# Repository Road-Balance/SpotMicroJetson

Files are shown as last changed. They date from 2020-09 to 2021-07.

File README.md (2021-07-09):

# SpotMicroAI - Road Balance version

### news
- There's Full video instruction about this project [youtube link](https://www.youtube.com/watch?v=RocfxXIWZd4&list=PLK2UKp8KOXe1ZRbSmcO3VvE_TNs66K6lA)
- And also there's Notion Note for whole project process [Notion Link](https://www.notion.so/SpotMicro-for-G-Camp-c541934a4bad4ad48d1e37ab94c10de8) 
- Those Contents above are written in Korean

SpotForward

## Abstract:

Let's build quadruped robot. Only requires few low-cost parts and this repository :)

## Hardware:

<center>
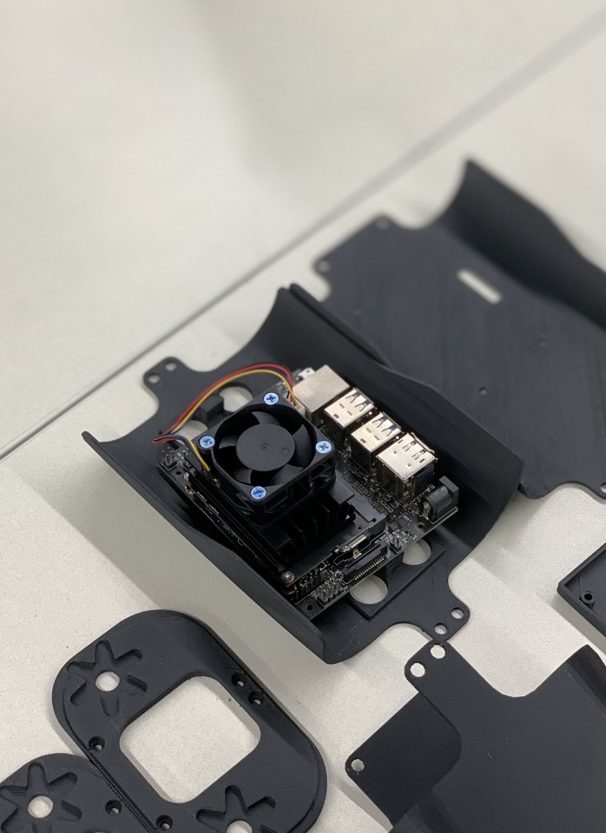
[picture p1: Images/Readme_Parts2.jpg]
    
</center>

The hardware for SpotMicroAI is designed to be both aesthetically pleasing as well as easily obtainable and readily available. Wherever possible standard screws, bolts, and bearings are used. Standard hobby grade servos are currently used for locomotion in development however, they don't appear to have sufficient power to drive the robot at more than the slowest speeds. Other options are currently being investigated (including high-voltage and brushless hobby servos typically used with RC cars) which we hope will lead to a balance between an economical as well as robust robot.

The vast majority of the hardware by volume is designed to be 3D printed. So far complete prints have been successful in PLA, though no technical barriers should exist to printing the robot in other material such as PETG, nylon, ABS, etc. The majority of parts require significant supports to print.

The files available both as STL and STP. As a community we have not yet settled on a servo for this project and therefore multiple versions of the hardware exist to support the physical dimensions of the servos and their respective servo horns. For the most up-to-date version of the hardware please visit: [https://www.thingiverse.com/thing:3761340](https://www.thingiverse.com/thing:3761340). Please see documentation for details as to which files correspond to which servo.

> BOM for Korean Commerce is added and here's the [google spreadsheet link](https://docs.google.com/spreadsheets/d/1UIJ1a0tUQx4ky75Ovr97hnKy3tkcdXQCYJl6zFl0juA/edit?usp=sharing)

## Electronics:

<center>
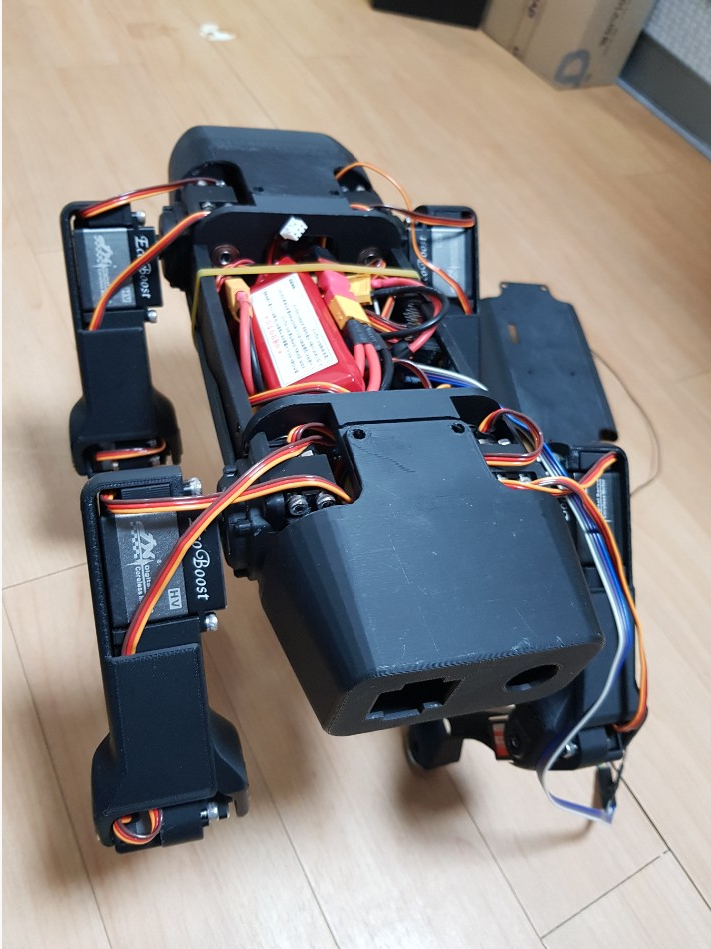
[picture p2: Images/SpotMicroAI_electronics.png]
    
</center>

The `Jetson Nano` operates at 5v, and the `PCA9658` for driving the servomotor operates at 6v. In this project, the electronic department was constructed using 7.9v LiPo batteries and `LM2596` DC Converter.

## PyBullet Simulation:
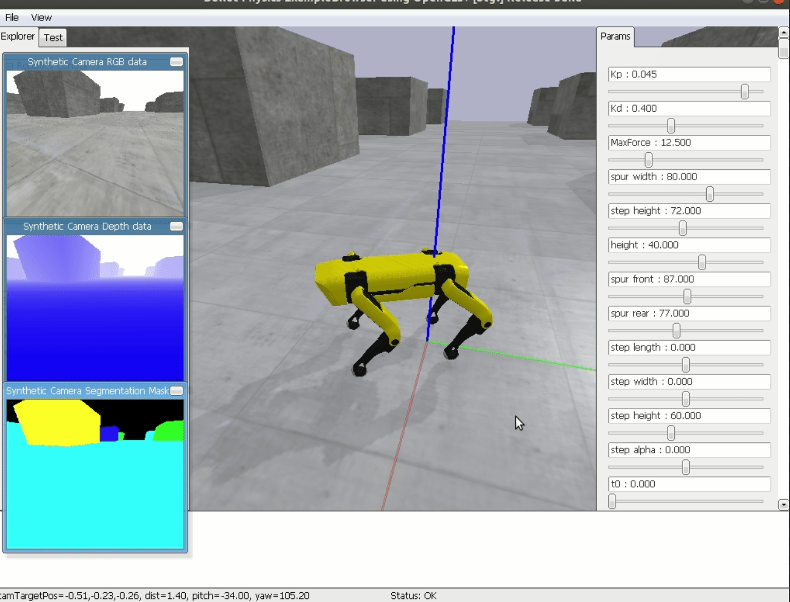
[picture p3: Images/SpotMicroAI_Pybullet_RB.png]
PyBullet Simulation


Before making the actual robot, we recommend experimenting with the kinematics and walking mechanism of the robot through simulation, and added a simulated environment built with pybullets to this end.

The walking mechanism can be understood through the adjustment of several parameters in simulation, and SpotMicro can also be controlled by the keyboard.

## Real Robots

SkyWalk

Finally, it's time to have a real robot and run it. Before uploading and operating the software after assembly, the debugging points such as calibration, center of gravity, and component placement of servo motor are organized and written in Readme file.

---

## Reference && Community

This repository originally forked from [FlorianWilk's Jetson Nano SpotMicro Project](https://github.com/FlorianWilk/SpotMicroAI)

COMPLETE DOCUMENTATION AND GETTING STARTED GUIDES CAN BE FOUND AT:
[https://spotmicroai.readthedocs.io/en/latest/](https://spotmicroai.readthedocs.io/en/latest/)

[spotmicroai.readthedocs.io](http://spotmicroai.readthedocs.io)

The best place to get started is to read the getting started documentation at [spotmicroai.readthedocs.io](spotmicroai.readthedocs.io). The documentation will eventually contain a complete tutorial for building a SpotMicroAI including where to source components, links to most recent 3D files for printing, assembly, and installing the software. It's being updated as we go.

For questions or more information please see the [Forums at SpotMicroAI.org](http://SpotMicroAI.org), or asked on slack. Join our slack at: [https://spotmicroai-inviter.herokuapp.com/](https://spotmicroai-inviter.herokuapp.com/)



BostonDynamics Spot robot: https://www.youtube.com/watch?v=wlkCQXHEgjA

Can you make it dance? join the challenge: https://www.youtube.com/watch?v=kHBcVlqpvZ8&list=PLp5v7U2tXHs3BYfe93GZwuUZLGsisapic&index=2

Original idea by KDY0523 https://www.thingiverse.com/thing:3445283

Some of the community videos: https://www.youtube.com/playlist?list=PLp5v7U2tXHs3BYfe93GZwuUZLGsisapic

* Join us in Slack: https://spotmicroai-inviter.herokuapp.com/
* Documentation: https://spotmicroai.readthedocs.io
* Forum http://spotmicroai.org/

This is the repository for simulation code, usually in combination with nVIDIA Jetson Nano board, of SpotMicro project.

In here you can find all the project repositories: **https://gitlab.com/custom_robots/spotmicro**

### Community:
The primary community discussions take place on SpotMicro.org. The message boards there contain a repository of topics which span hardware and software.

Real-time question-and-answer (or as close to real time as is possible when run by volunteers with full-time jobs and families) can happen on slack (LINK coming soon).

Other questions occasionally surface on other location such as on Thingiverse or on robotshop.com. We do our best answers these as we see them, but if you want to be heard the best way is either on SpotMicro.org or on slack.

As a community we do have some small expenses such as web hosting fees and occasional developing fees. In the future, we would also like to hold events and competitions. To anyone who finds enjoyment or education in this project we appreciate the financial support you're able to give. Donations coming soon.

All donations stay in the community and go towards future development.

If you use this worker will any work derived from it in academic publication please cite it as: *insert citation here*.

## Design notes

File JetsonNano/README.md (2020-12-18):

## SpotMicroAI for JetsonNano

TODO: Update this documentation

The Nano will use a 16 Channel PCA9685 I2C-Servo Driver to drive the 12 Servos for the Legs.
First of all all prepare your Jetson Nano as you see in the NVIDIA Documentation.

Then connect to it via SSH and:

```
$ sudo apt install python-dev python-pip python3-pip libfreetype6-dev libavdevice-dev libavfilter-dev libswscale-dev libavformat-dev libjpeg-dev build-essential -y
$ sudo apt install libsdl-dev libportmidi-dev libsdl-ttf2.0-dev libsdl-mixer1.2-dev libsdl-image1.2-dev -y 

$ pip install --upgrade pip
$ pip install --upgrade setuptools

$ cd SpotMiroAI/JetsonNano
$ pip3 install -U -r requirements.txt 
```

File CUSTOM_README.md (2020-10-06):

# SpotMicroJetson

Let's make SpotMicro with Nvidia Jetson Nano

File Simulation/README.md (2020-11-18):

## SpotMicroAI Pybullet Simulation

auto_gait

## Install Dependencies

```
sudo apt-get install python3 python3-pip
git clone https://github.com/Road-Balance/SpotMicroJetson.git

source <your-env>/bin/activate

cd SpotMicroJetson/Core
pip3 install -U -r requirements.txt 
```

## Automatic Gait with Keyboard Control

keyboard_control

Control SpotMicro in Pybullet Simulation with keyboard buttons 

```
# activate python venv
source <your-env>/bin/activate

# run automatic gait
# this needs administer privileges for keyboard multiprocessing
sudo python3 pybullet_automatic_gait.py

# if you're using venv
sudo <your-env-python-location> pybullet_automatic_gait.py
```

* `w` : go ahead
* `a` : go leftward
* `s` : go backward
* `d` : go rightward
* `q` : turn counter-clockwise
* `e` : turn clockwise
* `space` : Stop

Each time you press a button, it will move harder in that direction.

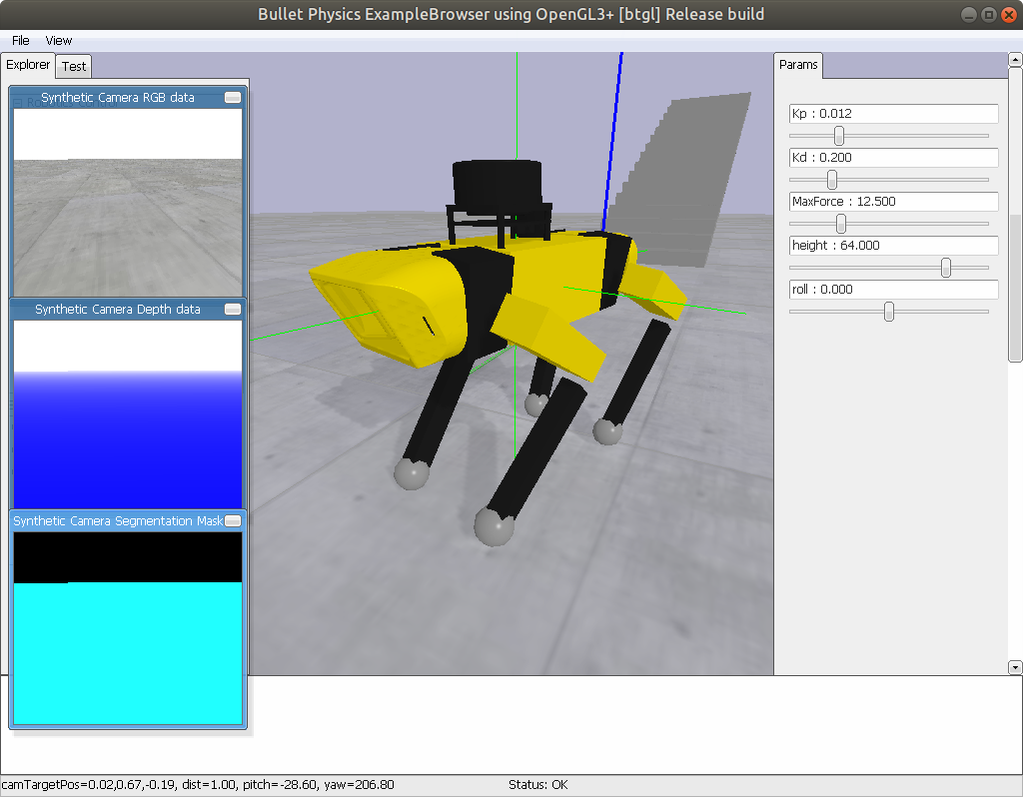
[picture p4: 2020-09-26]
Images/SpotMicroAI_pybullet_lidar.png

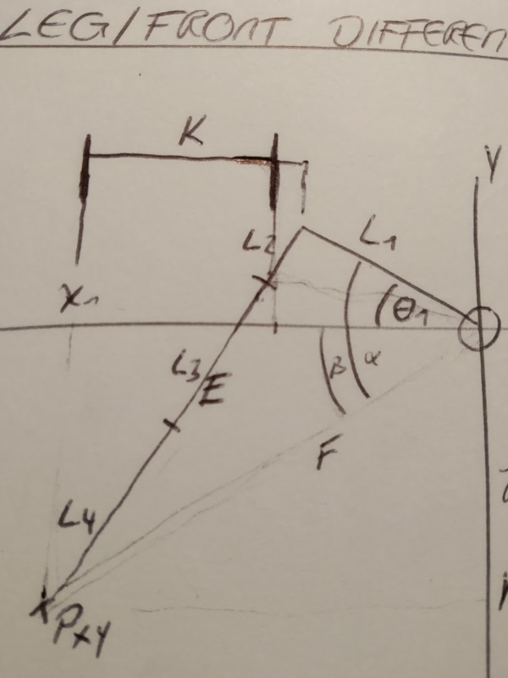
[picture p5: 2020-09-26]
Images/leg_front_k.jpg

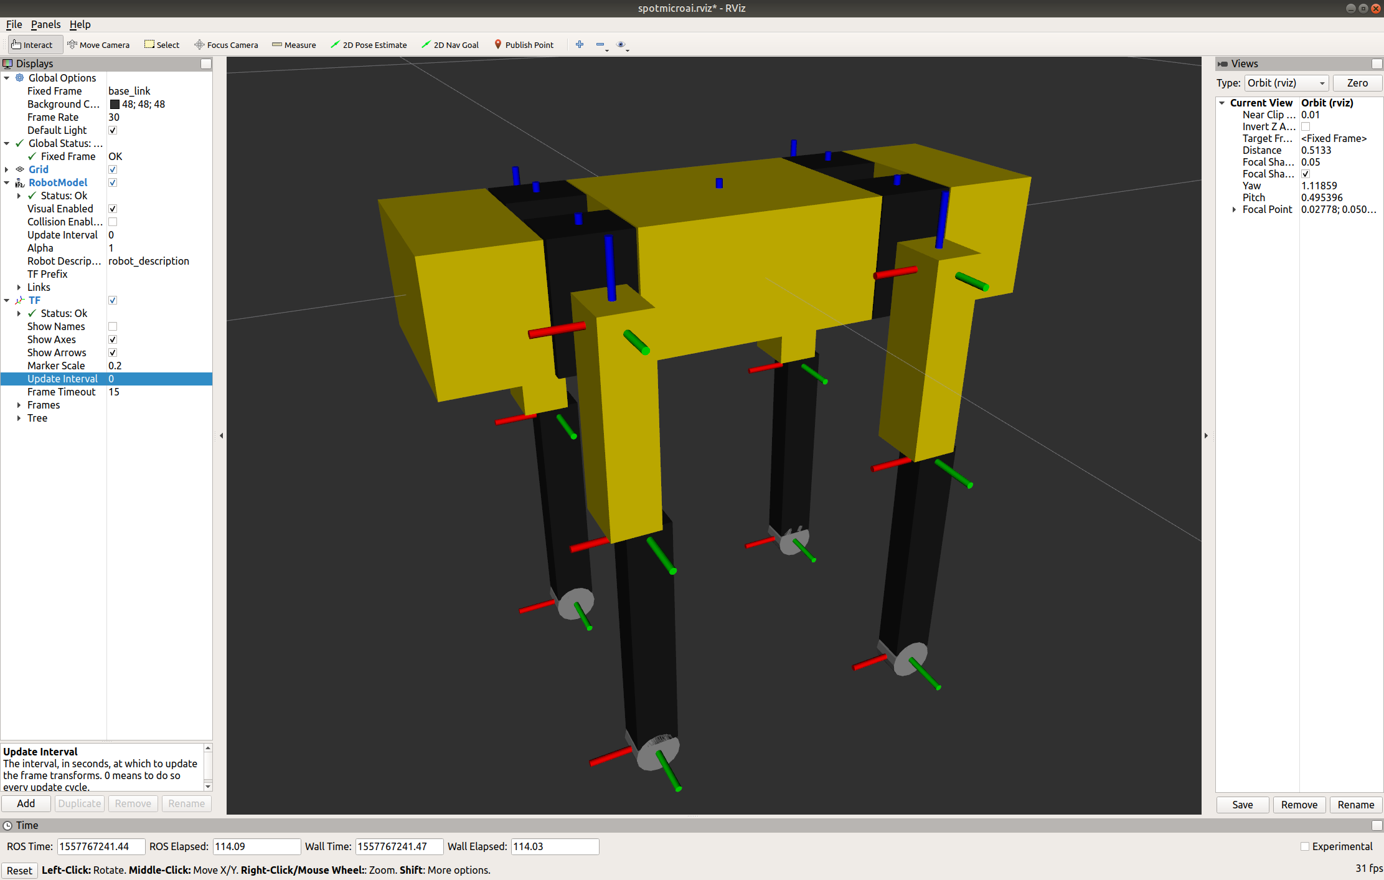
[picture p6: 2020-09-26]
Images/SpotMicroAI_rviz_color.png

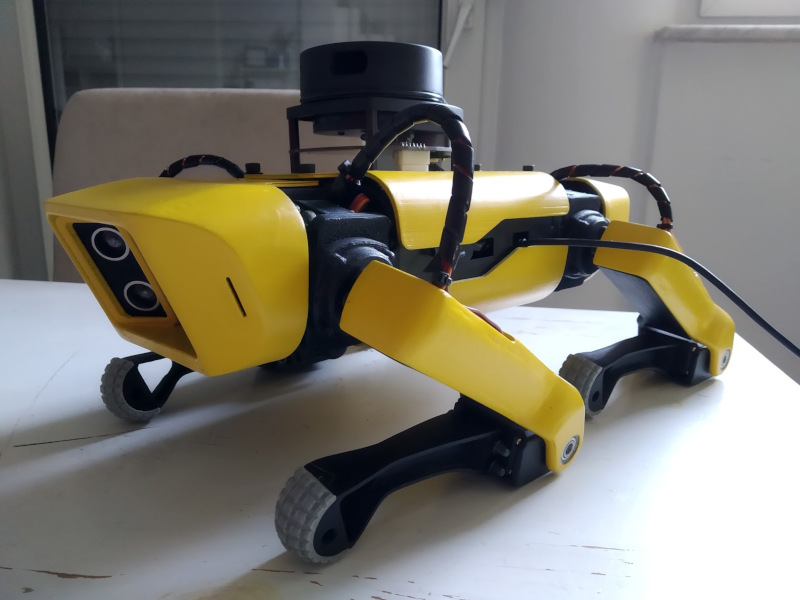
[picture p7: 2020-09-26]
Images/SpotMicroAI_complete_1.jpg

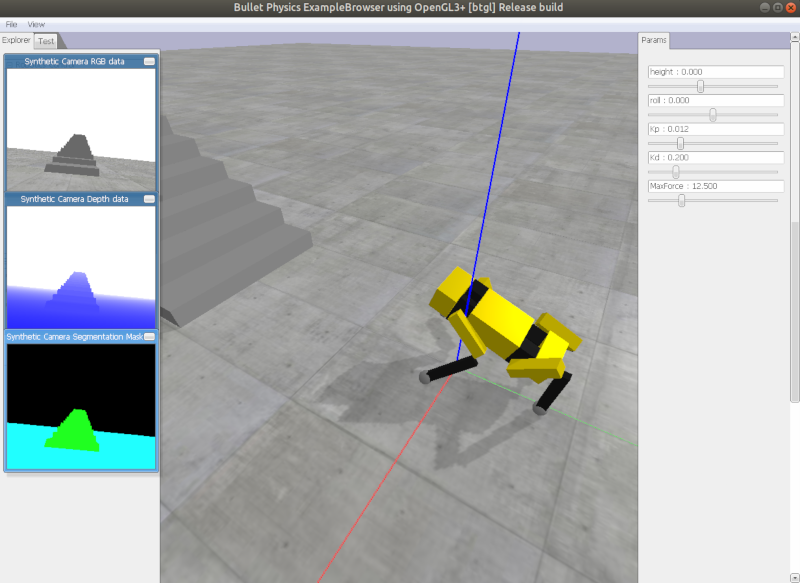
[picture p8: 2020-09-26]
Images/SpotMicroAI_stairs.png

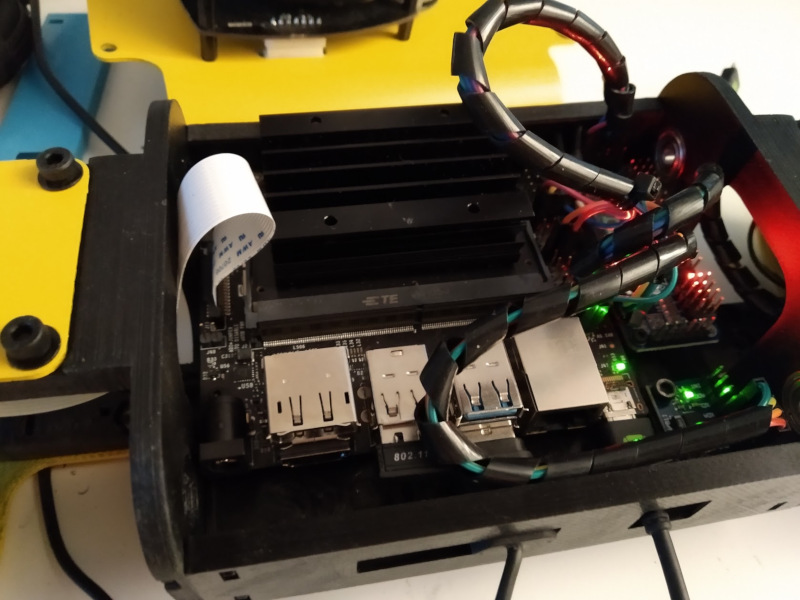
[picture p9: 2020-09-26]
Images/SpotMicroAI_jetson.jpg

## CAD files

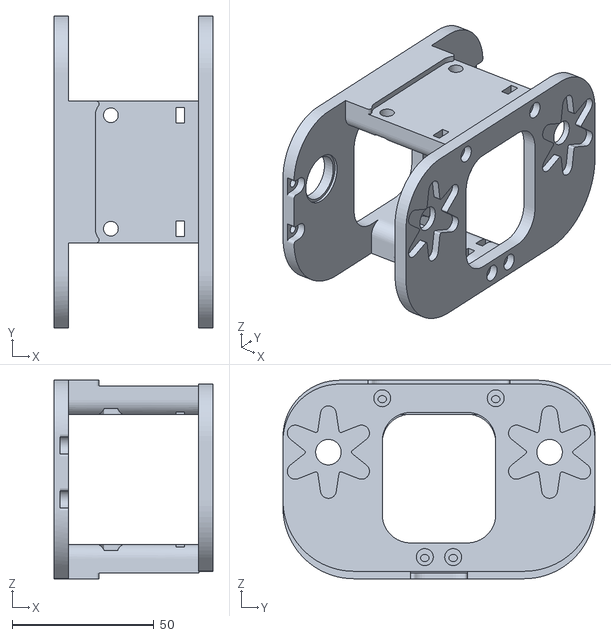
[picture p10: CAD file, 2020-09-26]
Parts/rearmain.stl
55.9 x 110.0 x 70.0

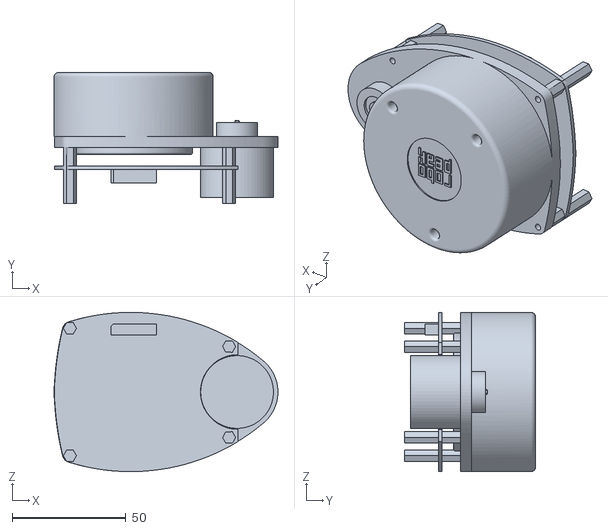
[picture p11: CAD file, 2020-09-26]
STL/lidar/rplidar_main.STL
98.5 x 57.7 x 70.0

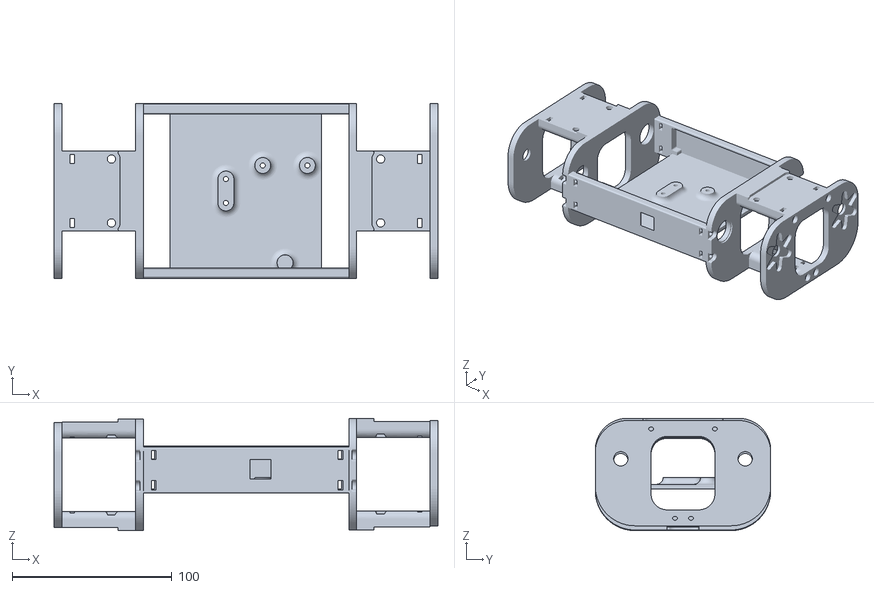
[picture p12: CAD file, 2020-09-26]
Parts/mainbody.stl
240.7 x 110.0 x 70.4

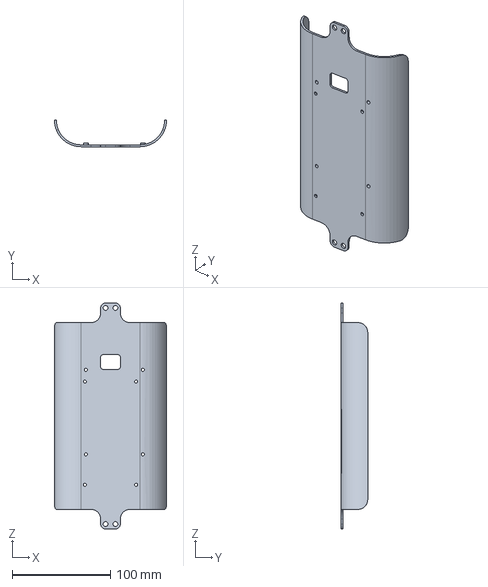
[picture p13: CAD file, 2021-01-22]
STEP_Files/Bottom_modi(long).stp
114.0 x 27.0 x 230.0 mm

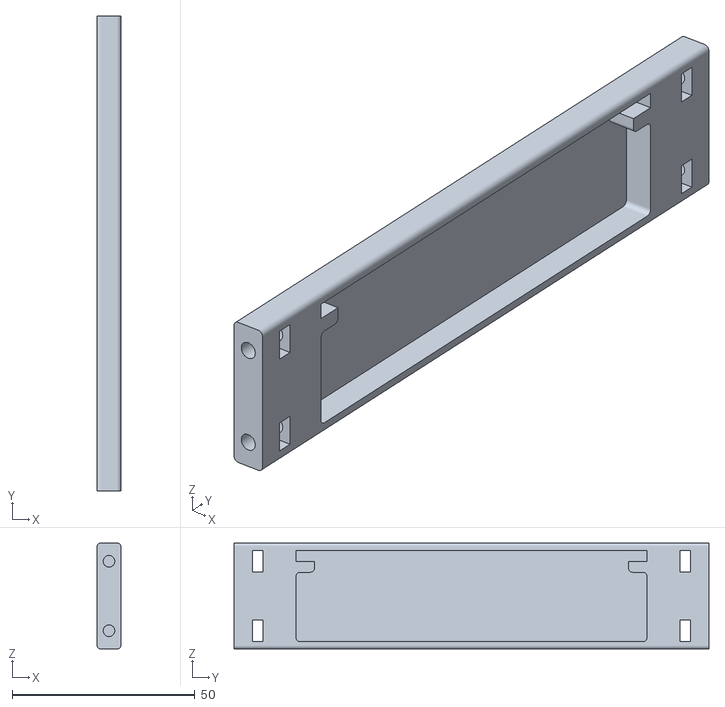
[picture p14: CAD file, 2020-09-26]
STL/files/R_side_plate.stl
6.50 x 130.0 x 29.0

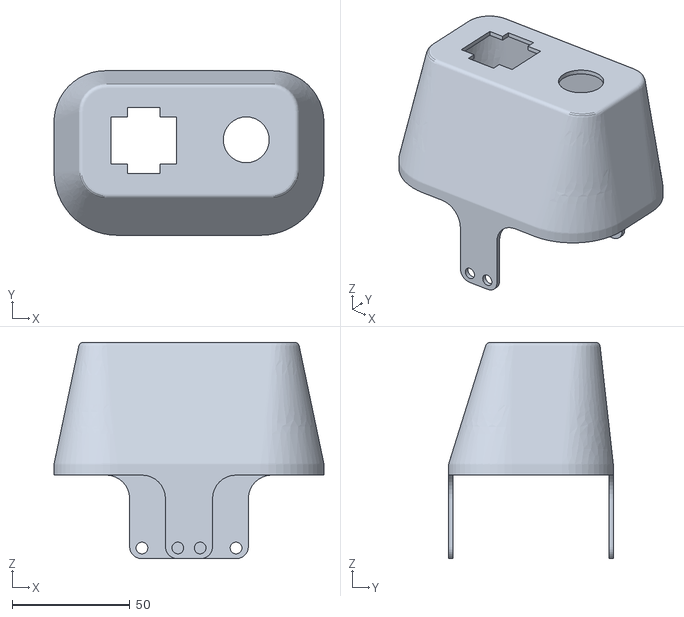
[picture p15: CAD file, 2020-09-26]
STL/rear2.stl
114.8 x 70.0 x 91.9

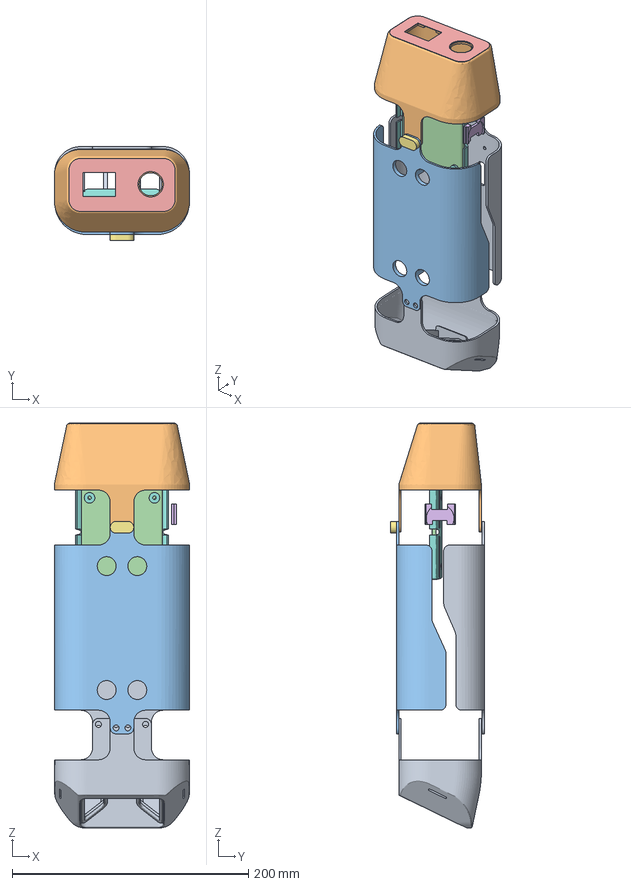
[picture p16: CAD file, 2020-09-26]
urdf/FreeCAD/SpotMicroAI_AdditionalParts.FCStd
114.8 x 79.5 x 343.2 mm
Top
Rear
Bottom
BatteryHolderHolder
rearlabel
LEDMount
ScrewGuard
F_cover

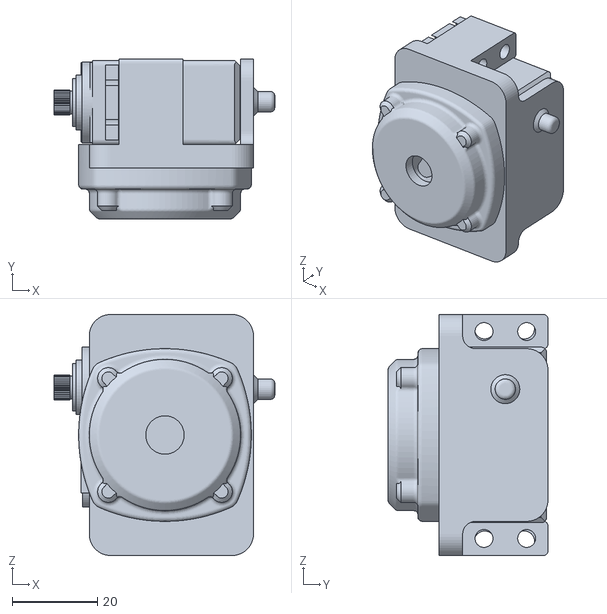
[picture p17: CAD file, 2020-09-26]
Parts/lshoulder.stl
51.7 x 37.5 x 56.5

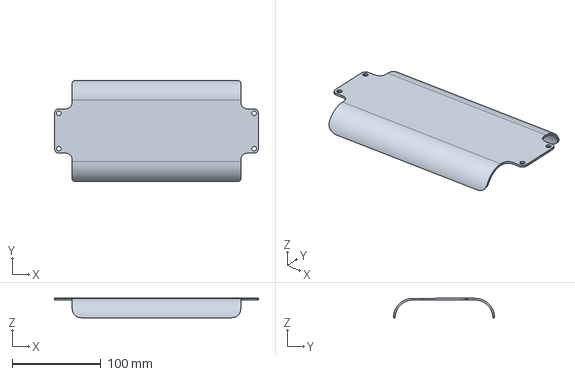
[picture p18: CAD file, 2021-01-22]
STEP_Files/Top_modi(long).stp
230.0 x 114.0 x 22.0 mm

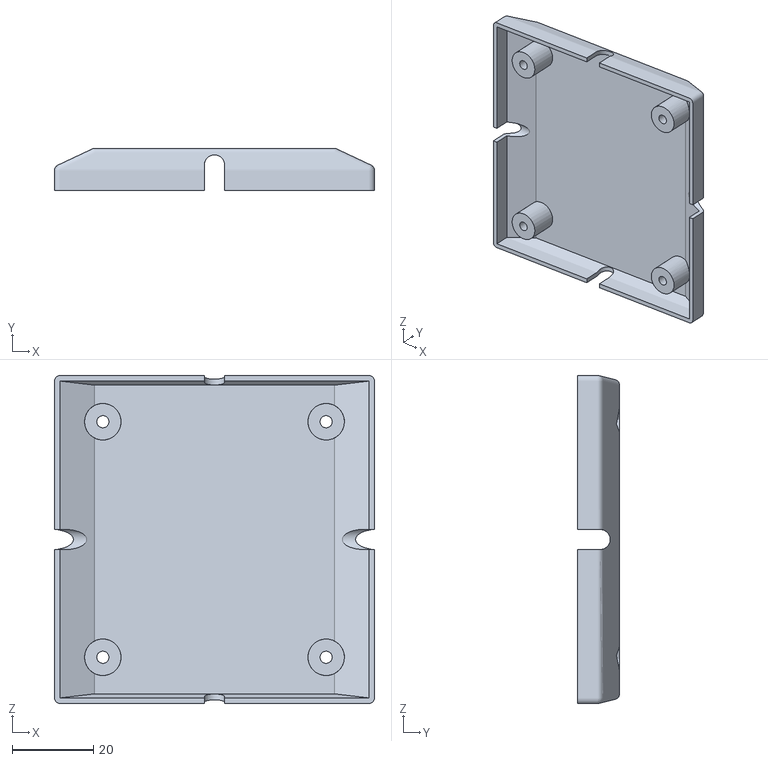
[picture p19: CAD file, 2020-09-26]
STL/batteryholder2.stl
78.8 x 10.4 x 80.8

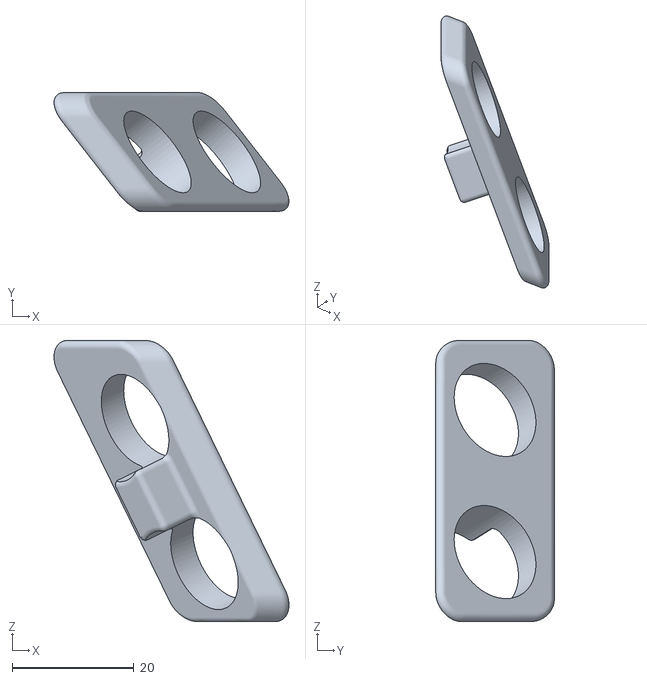
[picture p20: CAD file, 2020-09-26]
STL/files/L_ultra_sonic.stl
38.6 x 19.5 x 46.2

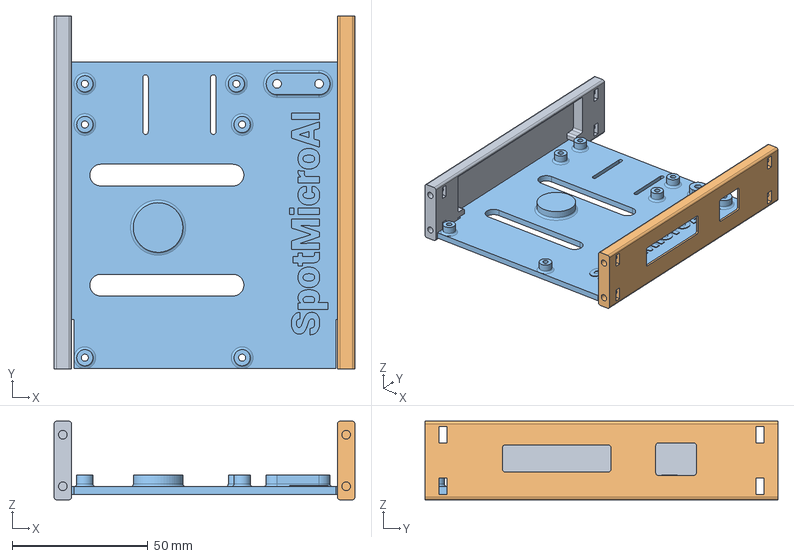
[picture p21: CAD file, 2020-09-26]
urdf/FreeCAD/SpotMicroAI_JetsonParts.FCStd
111.0 x 130.0 x 29.0 mm
rightSideplate
leftSideplate
JetsonPlateWithText

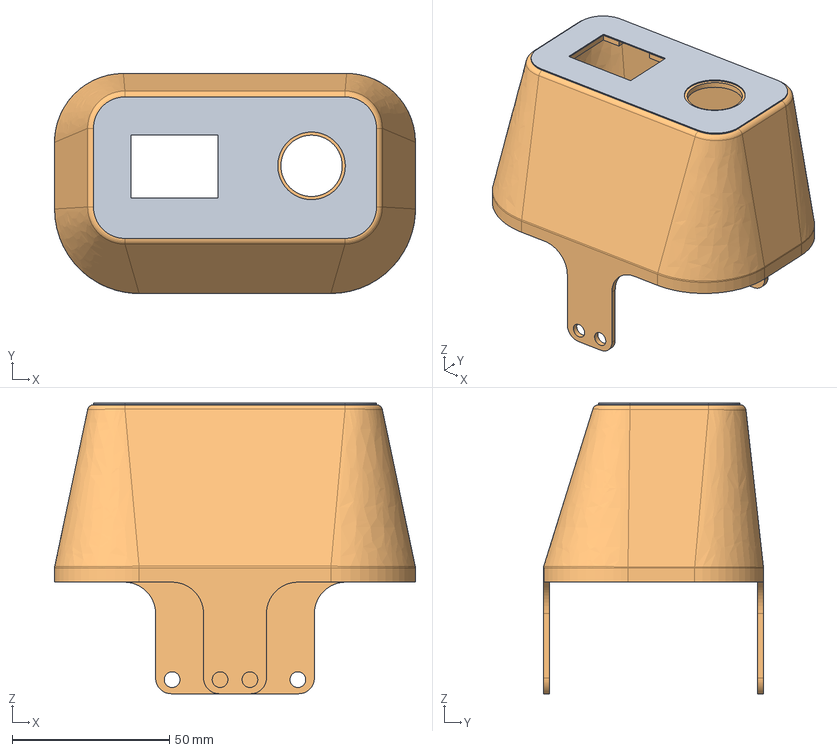
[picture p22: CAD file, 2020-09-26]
Parts/SpotMicroAI_Rear.FCStd
114.8 x 70.0 x 92.4 mm
rearlabel
Rear

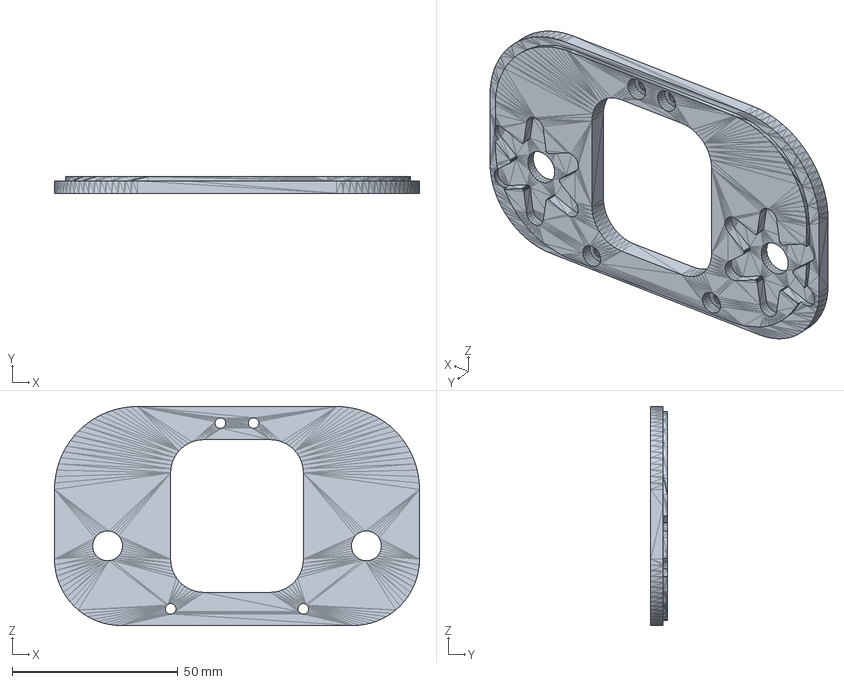
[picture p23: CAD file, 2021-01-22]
STEP_Files/O_shoulder_cls_grooved_modi.stp
110.0 x 5.00 x 66.0 mm

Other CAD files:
STL/bottom.stl
STL/files/non-mega_L_side_plate.stl
urdf/FreeCAD/SpotMicroAI_Top.FCStd
Parts/lfoot.stl
Parts/SpotMicroAI_Bottom.FCStd
Parts/SpotMicroAI_Top.FCStd
Parts/backpart.stl
Parts/frontpart.stl
Parts/jetsonPlate.stl
Parts/jetson_sidepart.stl
Parts/larm.stl
Parts/larm_cover.stl
Parts/rarm.stl
Parts/rarm_cover.stl
Parts/rfoot.stl
Parts/rshoulder.stl
STEP_Files/L_Side_Plate_modi(Long).stp
STEP_Files/R_Side_Plate_modi(long).stp
STL/batteryholder.stl
STL/files/B_cover.stl
STL/files/F_cover.stl
STL/files/F_cover_orig.stl
STL/files/F_shoulder.stl
STL/files/L_arm.stl
STL/files/L_arm_cover.stl
STL/files/L_arm_joint.stl
STL/files/L_side_plate.stl
STL/files/L_wrist.stl
STL/files/R_arm.stl
STL/files/R_arm_cover.stl
STL/files/R_arm_joint.stl
STL/files/R_cover.stl
STL/files/R_shoulder.stl
STL/files/R_ultra_sonic.stl
STL/files/R_wrist.stl
STL/files/T_cover.stl
STL/files/foot.stl
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

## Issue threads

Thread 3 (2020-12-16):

requirements.txt실행시 오류가 발생합니다.

jyes90, 2020-12-16:
Jetson Nano 사용중이며
강의자료에 나와있는 순서대로 작업을 진행했습니다.

(test_env) spot@spot-desktop:~/SpotMicroJetson/JetsonNano$ pip3 install -U -r requirements.txt
Collecting numpy-stl (from -r requirements.txt (line 1))
  Downloading https://files.pythonhosted.org/packages/8f/4b/885cfe0754b1692cb47eb1666d7b1beece4c8eeb99cffddc31ccc8725d23/numpy-stl-2.13.0.tar.gz (477kB)
    100% |████████████████████████████████| 481kB 816kB/s
Collecting matplotlib (from -r requirements.txt (line 2))
  Downloading https://files.pythonhosted.org/packages/7b/b3/7c48f648bf83f39d4385e0169d1b68218b838e185047f7f613b1cfc57947/matplotlib-3.3.3.tar.gz (37.9MB)
    100% |████████████████████████████████| 37.9MB 13kB/s

    Complete output from command python setup.py egg_info:
    Traceback (most recent call last):
      File "/home/spot/test_env/lib/python3.6/site-packages/setuptools/sandbox.py", line 154, in save_modules
        yield saved
      File "/home/spot/test_env/lib/python3.6/site-packages/setuptools/sandbox.py", line 195, in setup_context
        yield
      File "/home/spot/test_env/lib/python3.6/site-packages/setuptools/sandbox.py", line 250, in run_setup
        _execfile(setup_script, ns)
      File "/home/spot/test_env/lib/python3.6/site-packages/setuptools/sandbox.py", line 45, in _execfile
        exec(code, globals, locals)
      File "/tmp/easy_install-9y1jf38v/numpy-1.20.0rc1/setup.py", line 30, in <module>
        from setuptools import setup, find_packages, Extension
    RuntimeError: Python version >= 3.7 required.

    During handling of the above exception, another exception occurred:

    Traceback (most recent call last):
      File "<string>", line 1, in <module>
      File "/tmp/pip-build-u4n_e7fk/matplotlib/setup.py", line 298, in <module>
        cmdclass=cmdclass,
      File "/home/spot/test_env/lib/python3.6/site-packages/setuptools/__init__.py", line 128, in setup
        _install_setup_requires(attrs)
      File "/home/spot/test_env/lib/python3.6/site-packages/setuptools/__init__.py", line 123, in _install_setup_requires
        dist.fetch_build_eggs(dist.setup_requires)
      File "/home/spot/test_env/lib/python3.6/site-packages/setuptools/dist.py", line 513, in fetch_build_eggs
        replace_conflicting=True,
      File "/home/spot/test_env/lib/python3.6/site-packages/pkg_resources/__init__.py", line 774, in resolve
        replace_conflicting=replace_conflicting
      File "/home/spot/test_env/lib/python3.6/site-packages/pkg_resources/__init__.py", line 1057, in best_match
        return self.obtain(req, installer)
      File "/home/spot/test_env/lib/python3.6/site-packages/pkg_resources/__init__.py", line 1069, in obtain
        return installer(requirement)
      File "/home/spot/test_env/lib/python3.6/site-packages/setuptools/dist.py", line 580, in fetch_build_egg
        return cmd.easy_install(req)
      File "/home/spot/test_env/lib/python3.6/site-packages/setuptools/command/easy_install.py", line 698, in easy_install
        return self.install_item(spec, dist.location, tmpdir, deps)
      File "/home/spot/test_env/lib/python3.6/site-packages/setuptools/command/easy_install.py", line 724, in install_item
        dists = self.install_eggs(spec, download, tmpdir)
      File "/home/spot/test_env/lib/python3.6/site-packages/setuptools/command/easy_install.py", line 909, in install_eggs
        return self.build_and_install(setup_script, setup_base)
      File "/home/spot/test_env/lib/python3.6/site-packages/setuptools/command/easy_install.py", line 1177, in build_and_install
        self.run_setup(setup_script, setup_base, args)
      File "/home/spot/test_env/lib/python3.6/site-packages/setuptools/command/easy_install.py", line 1163, in run_setup
        run_setup(setup_script, args)
      File "/home/spot/test_env/lib/python3.6/site-packages/setuptools/sandbox.py", line 253, in run_setup
        raise
      File "/usr/lib/python3.6/contextlib.py", line 99, in __exit__
        self.gen.throw(type, value, traceback)
      File "/home/spot/test_env/lib/python3.6/site-packages/setuptools/sandbox.py", line 195, in setup_context
        yield
      File "/usr/lib/python3.6/contextlib.py", line 99, in __exit__
        self.gen.throw(type, value, traceback)
      File "/home/spot/test_env/lib/python3.6/site-packages/setuptools/sandbox.py", line 166, in save_modules
        saved_exc.resume()
      File "/home/spot/test_env/lib/python3.6/site-packages/setuptools/sandbox.py", line 141, in resume
        six.reraise(type, exc, self._tb)
      File "/home/spot/test_env/lib/python3.6/site-packages/setuptools/_vendor/six.py", line 685, in reraise
        raise value.with_traceback(tb)
      File "/home/spot/test_env/lib/python3.6/site-packages/setuptools/sandbox.py", line 154, in save_modules
        yield saved
      File "/home/spot/test_env/lib/python3.6/site-packages/setuptools/sandbox.py", line 195, in setup_context
        yield
      File "/home/spot/test_env/lib/python3.6/site-packages/setuptools/sandbox.py", line 250, in run_setup
        _execfile(setup_script, ns)
      File "/home/spot/test_env/lib/python3.6/site-packages/setuptools/sandbox.py", line 45, in _execfile
        exec(code, globals, locals)
      File "/tmp/easy_install-9y1jf38v/numpy-1.20.0rc1/setup.py", line 30, in <module>
        from setuptools import setup, find_packages, Extension
    RuntimeError: Python version >= 3.7 required.

    Edit setup.cfg to change the build options; suppress output with --quiet.

    BUILDING MATPLOTLIB
      matplotlib: yes [3.3.3]
          python: yes [3.6.9 (default, Oct  8 2020, 12:12:24)  [GCC 8.4.0]]
        platform: yes [linux]
     sample_data: yes [installing]
           tests: no  [skipping due to configuration]
          macosx: no  [Mac OS-X only]

    ----------------------------------------
Command "python setup.py egg_info" failed with error code 1 in /tmp/pip-build-u4n_e7fk/matplotlib/
위의 오류가 발생합니다.

kimsooyoung, 2020-12-16:
해당 부분 다음과 같이 수정 완료하였습니다.

혹 아래와 같은 수정 후에도 같은 문제가 반복된다면 알려주세요

감사합니다.

```
matplotlib==2.1.1
numpy==1.13.3
keyboard==0.13.5
getch==1.0
adafruit-circuitpython-servokit==1.3.0
Adafruit-PCA9685==1.0.1
Adafruit-SSD1306==1.6.2
adafruit-circuitpython-pca9685==3.3.2
smbus
psutil
```
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
kimsooyoung, 2020-12-17:
강의 자료 중에 다음과 같은 부분 따라하신 것 맞으실까요?

```bash
# 하드웨어 구동에 필요한 리눅스 패키지들 설치
$ sudo apt install python-dev python-pip python3-pip libfreetype6-dev libavdevice-dev libavfilter-dev libswscale-dev libavformat-dev libjpeg-dev build-essential -y
$ sudo apt install libsdl-dev libportmidi-dev libsdl-ttf2.0-dev libsdl-mixer1.2-dev libsdl-image1.2-dev -y
```

강의를 위해 순정 상태에서 확인 후 업데이트 하였는데, 저도 다시 확인해보겠습니다.

감사합니다.

jyes90, 2020-12-17:
네. 순정상태에서 14강 아래쪽의 다시 jetson 부분 그대로 따라하였습니다.

jyes90, 2020-12-17:
문제를 해결했습니다. pip, setuptools 버전의 문제인거같습니다.
sudo apt-get install python3-pip
sudo apt-get install python3-pip
pip install --upgrade setuptools
위 3가지 명령어 진행후에 해결되었습니다.

kimsooyoung, 2020-12-17:
정말 감사합니다!! 해당 내용 강의자료에도 추가 하였습니다.

좋은 하루 되세요 😀😀

## 다시 Jetson!!
# contribution from jyes90

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

jyes90, 2020-12-18:
저도 정말 감사드립니다.
그리고 제가 잘못올린 부분이 있네요.
sudo apt-get install python3-pip
pip install --upgrade pip
pip install --upgrade setuptools
이렇게 진행했습니다.

근데 sudo apt-get install python3-pip는 진행 안해도 될거같긴 합니다. 테스트를 다시 진행해보지 않아서 확실하진 않네요.
아래는 sudo apt-get install python3-pip를 실행했을 때 나온 내용입니다.
(spot_env) jetson@jetson-desktop:~/SpotMicroJetson/JetsonNano$ sudo apt-get install python3-pip
Reading package lists... Done
Building dependency tree
Reading state information... Done
python3-pip is already the newest version (9.0.1-2.3~ubuntu1.18.04.4).
0 upgraded, 0 newly installed, 0 to remove and 21 not upgraded.

기존코드에 보면 python3-pip 설치부분이 있어서 중복되기도 하고요. 그래서 제생각엔 기존 코드 뒤에
pip install --upgrade pip
pip install --upgrade setuptools
이 두가지가 추가되는게 좋을것 같습니다.

kimsooyoung, 2020-12-18:
👍 👍  상세한 설명 다시 한 번 감사드립니다. 말씀 주신 바와 같이 강의자료를 업로드 하였으며, `Readme.md` 또한 업데이트 하였습니다.

**jyes90**님 덕분에 다른 사용자분들께서도 해당 부분 어려움 없이 진행 가능하실 것 같습니다.

🎇 Github 첫 `Contribution`을 축하드립니다. 🎇

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

Closed 2020-12-18.

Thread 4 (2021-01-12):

automatic_gait 실행시 kinematics 모듈 실행 불가에러

aptxlee, 2021-01-12:
안녕하세요  automatic_gait.py를 실행하는데 지속적으로 no moduled not found kinematics.kinematics as kn 에러가 발생합니다. 우선은 지침을 모두 다 따라서 설치 하였지만 해당 임포트 에러가 지속적으로 발생하여 도움을 요청합니다. 제가 어느부분을 잘못한것인가요?

(lee-env) lee@lee-desktop:~/SpotMicroJetson/JetsonNano$ python start_automatic_gait.py
Traceback (most recent call last):
  File "start_automatic_gait.py", line 18, in <module>
    import Kinematics.Kinematics as kn
ModuleNotFoundError: No module named 'Kinematics.Kinematics'

개발환경 :제슨나노
에러 : kinmatics모듈 로드불가로인한 시스템 구동 불가

kimsooyoung, 2021-01-13:
안녕하세요 `aptxlee`님 이슈를 공유해주셔서 감사합니다. 우선 해당 모듈이 import 되는 과정을 짚고 넘어가고자 합니다.

* [다음 코드](https://github.com/Road-Balance/SpotMicroJetson/blob/ff864753422b70144ae6fcd4593f1c689b9bbadc/JetsonNano/start_automatic_gait.py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)를 보시면 import 할 모듈의 위치로 한단계 위의 상위 디렉토리를 추가하고 있습니다.
```python
from os import system, name
import sys
sys.path.append("..")
```

그렇기에 SpotMicroJetson/JetsonNano/ 에서 한 단계 위인 SpotMicroJetson/에 위치한 모듈들을 import 할 수 있게 됩니다.

지금 상황에서 SpotMicroJetson/Kinematics/를 보시면 아마 다음과 같은 파일들이 보이실 것입니다.

* Kinematic.ipynb
* KinematicMovements.ipynb
* README.md
* kinematicMotion.py
* kinematics.py

이들 중 우리가 import 해야 할 파일 이름은 `kinematics.py`이며, `import Kinematics.kinematicsas kn` 와 같이 가져올 수 있습니다.
하지만 `aptxlee`님의 질문을 보면 `import Kinematics.Kinematics as kn`로 되어 있네요

결론적으로, 아래와 같이 K를 소문자로 바꿔주시면 되지 않을까 싶습니다.

```python
# 질문 중
import Kinematics.Kinematics as kn

# 수정 후
import Kinematics.kinematics as kn
```

수정 후, 지속적으로 문제가 발생한다면 피드백을 남겨주세요!! 감사합니다. 👍

aptxlee, 2021-01-13:
제시하신 방법으로 코드를 변경하여 접근하였지만 같은문제가 계속 발생합니다. 혹시 절대 경로를 지정 넣어서 해도 문제가 없을까요?

kimsooyoung, 2021-01-13:
해결이 되지 않았다니 죄송합니다 😢
당장은 다음과 같은 디버깅이 떠오르는데요.

1. `kinematics.py`를 바로 **JetsonNano** 폴더에 복붙
2. 말씀주신 바와 같이 절대경로 지정

저 또한 디버깅하고 있겠습니다. 피드백 남겨주세요!!!

aptxlee, 2021-01-28:
경과 사항 공유 드립니다.
우선 기존의 임포트에러 문제는 해결하였습니다우분투 버전문제인가 싶어서 기존의 젯슨이미지가 아닌 강좌 자료에 있는 최신 이미지를 이용해 다시 sd카드를 포팅했으며 venv 를 활성화하고 예제코드를 실행시켜놓으면 해당 에러는 발생하지않았고 제대로 동작하였습니다.
다만 젯슨 나노의 기본은 파이썬 2.7로 설정되어있어서 이부분이 문제를 일으켰습니다. 그래서 https://seongkyun.github.io/others/2019/05/09/ubuntu_python/ 해당사이트의 방법대로 자동 실행 버전을 바꿔주고 우선 에러를 해결 하였습니다. 개인적으론 코드설명부분에 venv를 계속 활성화 시키고 코드를 실행할것같은 주의 문을 넣어주셔서 내용을 보충해주셨으면 합니다. 유투브영상은 너무길어서요 ㅎ
그리고 전자부에 각 부분의 어디가 어디로 연결되는지도 설명을 보충해주시면 좀더 좋을 자료가 될것같습니다. 문의에 응답해주셔서 감사드립니다.

kimsooyoung, 2021-01-29:
오랜 시간동안 고생 많으셨을텐데, 정말 감사드립니다.
동영상 강의는 제 소관이 아니라 수정이 불가하지만, 강의노트를 수정토록 하겠습니다.
전자부 또한 저도 부족함을 느끼고 있는데요, 차후에 설계와 더불어 PCB 제작을 기획하고 있으니 완료되면 추가토록 하겠습니다.

정말 감사드립니다. 좋은 하루 되세요!!! 👍

Closed 2021-01-29.

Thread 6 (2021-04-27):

모터 변경 후 frequency 문제

jyes90, 2021-04-27:
pca = list()
pca.append(PCA9685(i2c_bus0, address=0x40))
pca[-1].frequency = 330

모터를 CLS-200MD로 변경하여 구동을 하고 있는데, 위 모터는 frequency가 310으로 입력해야 제대로 동작을 합니다.

그래서 start_automatic_gait.py을 실행시키면 over180, under0가 지속적으로 나옵니다.

구동코드에서 frequency를 변경해줘야 할거같은데, 어디서 변경을 진행해야 하는가요?

그리고 확인해보니 CLS-200MD와 MG996R 두가지 모터가 회전방향이 서로 반대인데, 이부분은 어떻게 수정을 해야할까요?

ssh199898, 2021-04-28:
안녕하세요,

해당 상황은 저희가 이전에 배포하였던 servo_controller.py 파일의 라이브러리가 calibration 모듈과 맞지 않는 버전으로 배포되어 발생한 것으로 판단됩니다.

프로젝트에 새로운 **servo_controller_fix.py** 파일을 추가하였습니다.
동작은 동일하며, 서보모터 frequency, pulse width 등을 세밀하게 조정할 수 있도록 작성하였습니다.
해당 파일을 이용하여 시도해보시면 좋을 것 같습니다.

모터의 회전 방향이 반대일 경우, 우선적으로 해주셔야 할 작업은 다음과 같습니다.
1. _servo_offsets 의 값들을 바꿔주세요.
`180` -> `1`, `1` -> `180`으로 반대방향으로 바꾸어 주시면 됩니다.

2. thetas의 값의 부호를 바꿔주세요.
- `self._val_list[0] = self._servo_offsets[0] - self._thetas[0][2]` 에서 `-` 위치의 부호를 모두 뒤집어 바꿔주시거나,
-  thetas 리스트에 모두 -1을 곱해주시면 회전방향을 바꿀 수 있습니다.

감사합니다. :)

jyes90, 2021-04-28:
감사합니다. 일단 추가해주신 파일로 변경하여 실행을 해보았는데,
Initializing Servos
Initializing ServoKit
Done initializing
Under 0!!
Traceback (most recent call last):
  File "/home/bark/bark/JetsonNano/servo_controller.py", line 109, in <module>
    controller.servoRotate(thetas)
  File "/home/bark/bark/JetsonNano/servo_controller.py", line 96, in servoRotate
    self._kit.servo[x].angle = self._val_list[x]
AttributeError: 'Controllers' object has no attribute '_kit'
Exiting...
Cleaning up pins

이렇게 출력이 되면서 실행이 되질 않네요.

ssh199898, 2021-04-28:
안녕하세요,

해당 부분 파일 변경 과정에서 버그가 있었던 것으로 확인됩니다.
버그를 수정한 파일을 다시 업로드 하였습니다.

문제 발생시 문의 부탁드립니다. :)

jyes90, 2021-04-28:
답변 감사드립니다. 위의 문제는 해결이 되었습니다.

Closed 2021-04-28.

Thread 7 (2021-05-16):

특정 자세 추가 방법.

jyes90, 2021-05-16:
space를 입력하면 초기 자세로 돌아가는 것 처럼 특정 키를 입력하면 특정자세를 취하도록 하고 싶은데,

어디를 추가해야하는지 모르겠네요.

multiprocess_kb.py에 while 문 안에 self.resetStatus() 처럼 추가하면 될거같은데,

특정자세의 각도 등을 어떻게 입력을 해야하는지  감이 안잡히네요.

kimsooyoung, 2021-05-31:
안녕하세요.

해당 기능은 강의 내용을 통해 익힌 내용으로 충분히 구현 가능할 것이라 생각됩니다.

1. 원하시는 모습에 대한 모터의 각도를 모두 구한 뒤
2. 17강의 `pose` 제어 방식으로 함수를 구현합니다.
3. 24강의 키보드 제어 방식을 통해 c가 눌리면 해당 함수로 진입합니다.
4. 이 내용을 시뮬레이션에서 먼저 해보셔도 좋고, 바로 로봇으로 해보셔도 좋을 것 같습니다.

이런 순서로 진행하면 어떨까 싶습니다.
코드를 작성하여 직접 구현하는 것까지는 DH님의 끈기에 달려있다고 생각합니다.

원하시는 기능 구현하시기를 저도 응원하며 좋은 하루되세요
감사합니다.

김수영 드림

Closed 2021-06-03.

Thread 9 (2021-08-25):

Pybullet 오동작입니다.

suyong2, 2021-08-25:
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
안녕하세요.
g.camp강의로 알게됐습니다만, Pybullet 시뮬실행하면 첨부사진처럼 공중에떠있어 w,s 눌러도 이동이 안되고 허공에서 동작하는데, 바닥으로 내릴방법은 없는지요?
좋은 강의 감사드리며 방법아시면 답변부탁드리겠습니다.

kimsooyoung, 2021-09-01:
Sorry for late reply,

If you want the robot to walk on the ground, change below lines as follows

```
robot=spotmicroai.Robot(True,True,reset)

to

robot=spotmicroai.Robot(False,True,reset)
```

suyong2, 2021-09-05:
잘되네요. It works well. Thanks.

Closed 2021-09-05.

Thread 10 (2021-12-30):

모터드라이버문의

turtlebot1024, 2021-12-30:
안녕하세요
동작중 모터드라이버pca9685가 타는일이생겨문의드립니다.
cls모터를사용하였고 pca에는 약 5V를 V+에연결하여 6개의모터를 동작시켰는데요
부하를 조금받자마자 드라이버소손이 발생했습니다.
5V로는 cls모터가충분한출력토크생성을못하는것같은데 혹시 다른방법이있을지문의드립니다. 그리고 충분한 토크생성이안될경우 저와같이 소손이일어날수있는지도궁금합니다. 감사합니다

kimsooyoung, 2022-01-01:
pca9685가 부하에 대응이 쉽지 않다는 것은 저도 마찬가지였습니다.
때문에, 모든 모터 움직임이 최대한 자유로운 상태에서 작업을 하신 뒤, 이후 충분한 전류를 갖는 전원으로 개발하시기를 추천드립니다.

저의 경우 7.4V Lipo 베터리 + DC/DC Converter를 사용하여 Step Down한 뒤 연결하여 사용하였습니다.

Closed 2022-01-08.

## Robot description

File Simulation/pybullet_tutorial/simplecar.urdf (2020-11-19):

<?xml version="1.0"?> 
<robot name="simplecar">
    <!-- Colors --> 
    <material name="black"> 
        <color rgba="0 0 0 1"/>
    </material>
    <material name="blue"> 
        <color rgba="0.6 0.7 0.8 1"/>
    </material>


    <!-- Base Frame of Car --> 
    <link name="base_link">
        <visual> 
            <geometry> 
                <box size="0.5 0.3 0.1"/>
            </geometry>
            <material name="blue"/>
        </visual>
        <inertial> 
            <mass value="6"/>
            <inertia ixx="0.2" ixy="0" ixz="0" iyy="0.2" iyz="0.0" izz="0.2"/>
        </inertial> 
    </link> 


    <!-- Left Front Wheel -->
    <link name="left_front_wheel">
        <visual> 
            <geometry> 
                <cylinder length="0.05" radius="0.1"/>
            </geometry>
            <origin rpy="1.57075 1.57075 0"/>
            <material name="black"/>
        </visual>
        <collision> 
             <geometry> 
                <cylinder length="0.05" radius="0.1"/>
            </geometry>
            <origin rpy="1.57075 1.57075 0"/>
        </collision> 
        <inertial> 
            <origin rpy="1.57075 1.57075 0"/>
            <mass value="0.3"/>
            <inertia ixx="0.4" ixy="0" ixz="0" iyy="0.4" iyz="0.0" izz="0.2"/>
        </inertial> 
    </link> 
    <joint name="left_hinge_to_left_front_wheel" type="continuous">
        <parent link="left_hinge"/>
        <child link="left_front_wheel"/> 
        <axis xyz="0 1 0"/>
        <origin xyz="0 0.2 0"/>
    </joint>
    <!-- Left Front Wheel - Hinge -->
    <link name="left_hinge">
        <visual> 
            <geometry> 
                <box size="0.20 0.02 0.02"/>
            </geometry>
            <origin xyz="0 0.1 0 " rpy="0 0 1.57075"/>
            <material name="black"/>
        </visual>
        <inertial> 
            <origin rpy="0 0 1.57075"/>
            <mass value="0.01"/>
            <inertia ixx="5E-6" ixy="0" ixz="0" iyy="5E-6" iyz="0" izz="5E-6"/>
        </inertial> 
    </link> 
    <joint name="base_to_left_hinge" type="revolute">
        <parent link="base_link"/>
        <child link="left_hinge"/> 
        <axis xyz="0 0 1"/>
        <origin xyz="0.2 0.0 0"/>
        <limit effort="100" lower="-0.5" upper="0.5" velocity="100"/>
    </joint>
    <!-- Right Front Wheel -->
    <link name="right_front_wheel">
        <visual> 
            <geometry> 
                <cylinder length="0.05" radius="0.1"/>
            </geometry>
            <origin rpy="-1.57075 -1.57075 0"/>
            <material name="black"/>
        </visual>
        <collision> 
             <geometry> 
                <cylinder length="0.05" radius="0.1"/>
            </geometry>
            <origin rpy="-1.57075 -1.57075 0"/>
        </collision> 
        <inertial> 
            <origin rpy="-1.57075 -1.57075 0"/>
            <mass value="0.3"/>
            <inertia ixx="0.4" ixy="0" ixz="0" iyy="0.4" iyz="0.0" izz="0.2"/>
        </inertial> 
    </link> 
    <joint name="right_hinge_to_right_front_wheel" type="continuous">
        <parent link="right_hinge"/>
        <child link="right_front_wheel"/> 
        <axis xyz="0 1 0"/>
        <origin xyz="0 -0.2 0"/>
    </joint>
    <!-- Right Front Wheel - Hinge -->
    <link name="right_hinge">
        <visual> 
            <geometry> 
                <box size="0.20 0.02 0.02"/>
            </geometry>
            <origin xyz="0 -0.1 0 " rpy="0 0 -1.57075"/>
            <material name="black"/>
        </visual>
        <inertial> 
            <origin rpy="0 0 -1.57075"/>
            <mass value="0.01"/>
            <inertia ixx="5E-6" ixy="0" ixz="0" iyy="5E-6" iyz="0" izz="5E-6"/>
        </inertial> 
    </link> 
    <joint name="base_to_right_hinge" type="revolute">
        <parent link="base_link"/>
        <child link="right_hinge"/> 
        <axis xyz="0 0 1"/>
        <origin xyz="0.2 0 0"/>
        <limit effort="100" lower="-0.5" upper="0.5" velocity="100"/>
    </joint>
    <!-- Left Back Wheel -->
    <link name="left_back_wheel">
        <visual> 
            <geometry> 
                <cylinder length="0.05" radius="0.1"/>
            </geometry>
            <origin rpy="1.57075 1.57075 0"/>
            <material name="black"/>
        </visual>
        <collision> 
             <geometry> 
                <cylinder length="0.05" radius="0.1"/>
            </geometry>
            <origin rpy="1.57075 1.57075 0"/>
        </collision> 
        <inertial> 
            <origin rpy="1.57075 1.57075 0"/>
            <mass value="0.3"/>
            <inertia ixx="0.4" ixy="0" ixz="0" iyy="0.4" iyz="0.0" izz="0.2"/>
        </inertial> 
    </link> 
    <joint name="base_to_left_back_wheel" type="continuous">
        <parent link="base_link"/>
        <child link="left_back_wheel"/> 
        <axis xyz="0 1 0"/>
        <origin xyz="-0.2 0.175 0"/>
    </joint>
    <!-- Right Back Wheel -->
    <link name="right_back_wheel">
        <visual> 
            <geometry> 
                <cylinder length="0.05" radius="0.1"/>
            </geometry>
            <origin rpy="-1.57075 -1.57075 0"/>
            <material name="black"/>
        </visual>
        <collision> 
             <geometry> 
                <cylinder length="0.05" radius="0.1"/>
            </geometry>
            <origin rpy="-1.57075 -1.57075 0"/>
        </collision> 
        <inertial> 
            <origin rpy="-1.57075 -1.57075 0"/>
            <mass value="0.3"/>
            <inertia ixx="0.4" ixy="0" ixz="0" iyy="0.4" iyz="0.0" izz="0.2"/>
        </inertial> 
    </link> 
    <joint name="base_to_right_back_wheel" type="continuous">
        <parent link="base_link"/>
        <child link="right_back_wheel"/> 
        <axis xyz="0 1 0"/>
        <origin xyz="-0.2 -0.175 0"/>
    </joint>
</robot>

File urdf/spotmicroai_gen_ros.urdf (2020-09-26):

<?xml version="1.0" encoding="utf-8"?>
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
<robot name="SpotMicroAI" xmlns:xacro="http://www.ros.org/wiki/xacro">
  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
  <link name="base_link">
    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
    <inertial>
      <mass value="2.80"/>
      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
    </inertial>
  </link>
  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
  <link name="lidar_link">
    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
    <inertial>
      <mass value="0.50"/>
      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
    </inertial>
  </link>
  <joint name="base_lidar" type="fixed">
    <parent link="base_link"/>
    <child link="lidar_link"/>
    <origin xyz="0 0 0.035"/>
  </joint>
  <link name="rear_link">
    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
    <inertial>
      <mass value="0.20"/>
      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
    </inertial>
  </link>
  <joint name="base_rear" type="fixed">
    <parent link="base_link"/>
    <child link="rear_link"/>
  </joint>
  <link name="front_link">
    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
    <inertial>
      <mass value="0.20"/>
      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
    </inertial>
  </link>
  <joint name="base_front" type="fixed">
    <parent link="base_link"/>
    <child link="front_link"/>
  </joint>
  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
  <link name="front_left_shoulder_link">
    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
    <inertial>
      <mass value="0.10"/>
      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
    </inertial>
  </link>
  <link name="front_left_leg_link_cover">
    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
  </link>
  <link name="front_left_leg_link">
    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
    <inertial>
      <mass value="0.15"/>
      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
    </inertial>
  </link>
  <link name="front_left_foot_link">
    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
    <inertial>
      <mass value="0.1"/>
      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
    </inertial>
  </link>
  <link name="front_left_toe_link">
    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
    <inertial>
      <mass value="0.05"/>
      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
    </inertial>
  </link>
  <joint name="front_left_shoulder" type="revolute">
    <parent link="base_link"/>
    <child link="front_left_shoulder_link"/>
    <axis xyz="1 0 0"/>
    <origin rpy="0 0 0" xyz="-0.093 -0.036 0"/>
    <limit effort="1000.0" lower="-0.548" upper="0.548" velocity="0.7"/>
    <dynamics damping="0.0" friction="0.5"/>
  </joint>
  <joint name="front_left_leg" type="revolute">
    <parent link="front_left_shoulder_link"/>
    <child link="front_left_leg_link"/>
    <axis xyz="0 1 0"/>
    <origin rpy="0 0 0" xyz="0 -0.052 0"/>
    <limit effort="1000.0" lower="-2.666" upper="1.548" velocity="0.5"/>
    <dynamics damping="0.0" friction="0.0"/>
  </joint>
  <joint name="front_left_leg_cover_joint" type="fixed">
    <parent link="front_left_leg_link"/>
    <child link="front_left_leg_link_cover"/>
    <origin xyz="0 0 0"/>
  </joint>
  <joint name="front_left_foot" type="revolute">
    <parent link="front_left_leg_link"/>
    <child link="front_left_foot_link"/>
    <axis xyz="0 1 0"/>
    <origin rpy="0 0 0" xyz="-0.01 0 -0.12"/>
    <limit effort="1000.0" lower="-0.1" upper="2.59" velocity="0.5"/>
    <dynamics damping="0.0" friction="0.5"/>
  </joint>
  <joint name="front_left_toe" type="fixed">
    <parent link="front_left_foot_link"/>
    <child link="front_left_toe_link"/>
    <origin xyz="0 0 -0.115"/>
  </joint>
  <link name="front_right_shoulder_link">
    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
    <inertial>
      <mass value="0.10"/>
      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
    </inertial>
  </link>
  <link name="front_right_leg_link_cover">
    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
  </link>
  <link name="front_right_leg_link">
    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
    <inertial>
      <mass value="0.15"/>
      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
    </inertial>
  </link>
  <link name="front_right_foot_link">
    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
    <inertial>
      <mass value="0.1"/>
      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
    </inertial>
  </link>
  <link name="front_right_toe_link">
    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
    <inertial>
      <mass value="0.05"/>
      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
    </inertial>
  </link>
  <joint name="front_right_shoulder" type="revolute">
    <parent link="base_link"/>
    <child link="front_right_shoulder_link"/>
    <axis xyz="1 0 0"/>
    <origin rpy="0 0 0" xyz="-0.093 0.036 0"/>
    <limit effort="1000.0" lower="-0.548" upper="0.548" velocity="0.7"/>
    <dynamics damping="0.0" friction="0.5"/>
  </joint>
  <joint name="front_right_leg" type="revolute">
    <parent link="front_right_shoulder_link"/>
    <child link="front_right_leg_link"/>
    <axis xyz="0 1 0"/>
    <origin rpy="0 0 0" xyz="0 0.052 0"/>
    <limit effort="1000.0" lower="-2.666" upper="1.548" velocity="0.5"/>
    <dynamics damping="0.0" friction="0.0"/>
  </joint>
  <joint name="front_right_leg_cover_joint" type="fixed">
    <parent link="front_right_leg_link"/>
    <child link="front_right_leg_link_cover"/>
    <origin xyz="0 0 0"/>
  </joint>
  <joint name="front_right_foot" type="revolute">
    <parent link="front_right_leg_link"/>
    <child link="front_right_foot_link"/>
    <axis xyz="0 1 0"/>
    <origin rpy="0 0 0" xyz="-0.01 0 -0.12"/>
    <limit effort="1000.0" lower="-0.1" upper="2.59" velocity="0.5"/>
    <dynamics damping="0.0" friction="0.5"/>
  </joint>
  <joint name="front_right_toe" type="fixed">
    <parent link="front_right_foot_link"/>
    <child link="front_right_toe_link"/>
    <origin xyz="0 0 -0.115"/>
  </joint>
  <link name="rear_left_shoulder_link">
    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
    <inertial>
      <mass value="0.10"/>
      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
    </inertial>
  </link>
  <link name="rear_left_leg_link_cover">
    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
  </link>
  <link name="rear_left_leg_link">
    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
    <inertial>
      <mass value="0.15"/>
      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
    </inertial>
  </link>
  <link name="rear_left_foot_link">
    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
    <inertial>
      <mass value="0.1"/>
      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
    </inertial>
  </link>
  <link name="rear_left_toe_link">
    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
    <inertial>
      <mass value="0.05"/>
      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
    </inertial>
  </link>
  <joint name="rear_left_shoulder" type="revolute">
    <parent link="base_link"/>
    <child link="rear_left_shoulder_link"/>
    <axis xyz="1 0 0"/>
    <origin rpy="0 0 0" xyz="0.093 -0.036 0"/>
    <limit effort="1000.0" lower="-0.548" upper="0.548" velocity="0.7"/>
    <dynamics damping="0.0" friction="0.5"/>
  </joint>
  <joint name="rear_left_leg" type="revolute">
    <parent link="rear_left_shoulder_link"/>
    <child link="rear_left_leg_link"/>
    <axis xyz="0 1 0"/>
    <origin rpy="0 0 0" xyz="0 -0.052 0"/>
    <limit effort="1000.0" lower="-2.666" upper="1.548" velocity="0.5"/>
    <dynamics damping="0.0" friction="0.0"/>
  </joint>
  <joint name="rear_left_leg_cover_joint" type="fixed">
    <parent link="rear_left_leg_link"/>
    <child link="rear_left_leg_link_cover"/>
    <origin xyz="0 0 0"/>
  </joint>
  <joint name="rear_left_foot" type="revolute">
    <parent link="rear_left_leg_link"/>
    <child link="rear_left_foot_link"/>
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

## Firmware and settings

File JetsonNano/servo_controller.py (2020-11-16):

import sys
sys.path.append("..")

import Kinematics.kinematics as kn
import numpy as np
from adafruit_servokit import ServoKit
import board
import busio
import time

class Controllers:
    def __init__(self):

        print("Initializing Servos")
        self._i2c_bus0=(busio.I2C(board.SCL_1, board.SDA_1))
        print("Initializing ServoKit")
        self._kit = ServoKit(channels=16, i2c=self._i2c_bus0, address=0x40)
        self._kit2 = ServoKit(channels=16, i2c=self._i2c_bus0, address=0x41)
        print("Done initializing")

        #1 by 12 array
        self.MOTOR_LEG_FRONT = 0
        self.MOTOR_LEG_BACK = 6
        self.MOTOR_LEG_LEFT = 0 
        self.MOTOR_LEG_RIGHT = 3
        self.MOTOR_LEG_SHOULDER = 2
        self.MOTOR_LEG_UPPER = 1
        self.MOTOR_LEG_LOWER = 0

        #4 by 3 matrix
        self.SIM_LEG_FRONT = 0
        self.SIM_LEG_BACK = 2
        self.SIM_LEG_LEFT = 0
        self.SIM_LEG_RIGHT = 1
        self.SIM_LEG_THETA1 = 0
        self.SIM_LEG_THETA2 = 1
        self.SIM_LEG_THETA3 = 2

        # [0]~[2] : 왼쪽 앞 다리 // [3]~[5] : 오른쪽 앞 다리 // [6]~[8] : 왼쪽 뒷 다리 // [9]~[11] : 오른쪽 뒷 다리
        # centered position perpendicular to the ground
        self._servo_offsets = [170, 85, 90, 1, 95, 90, 172, 90, 90, 1, 90, 95]
        #self._servo_offsets = [90, 90, 90, 90, 90, 90, 90, 90, 90, 90, 90, 90]

        self._val_list = np.zeros(12) #[ x for x in range(12) ]

        # All Angles for Leg 3 * 4 = 12 length
        self._thetas = []

    def getDegreeAngles(self, La):
        # radian to degree
        La *= 180/np.pi
        La = [ [ int(x) for x in y ] for y in La ]

        self._thetas = La

    # Angle mapping from radian to servo angles
    def angleToServo(self, La):

        self.getDegreeAngles(La)

        #FL Lower
        self._val_list[0] = self._servo_offsets[0] - self._thetas[0][2]
        #FL Upper
        self._val_list[1] = self._servo_offsets[1] - self._thetas[0][1]    
        #FL Shoulder
        self._val_list[2] = self._servo_offsets[2] + self._thetas[0][0]

        #FR Lower
        self._val_list[3] = self._servo_offsets[3] + self._thetas[1][2]
        #FR Upper
        self._val_list[4] = self._servo_offsets[4] + self._thetas[1][1]    
        #FR Shoulder
        self._val_list[5] = self._servo_offsets[5] - self._thetas[1][0]

        #BL Lower
        self._val_list[6] = self._servo_offsets[6] - self._thetas[2][2]
        #BL Upper
        self._val_list[7] = self._servo_offsets[7] - self._thetas[2][1]    
        #BL Shoulder, Formula flipped from the front
        self._val_list[8] = self._servo_offsets[8] - self._thetas[2][0]

        #BR Lower. 
        self._val_list[9] = self._servo_offsets[9] + self._thetas[3][2]
        #BR Upper
        self._val_list[10] = self._servo_offsets[10] + self._thetas[3][1]    
        #BR Shoulder, Formula flipped from the front
        self._val_list[11] = self._servo_offsets[11] + self._thetas[3][0]     

    def getServoAngles(self):
        return self._val_list

    def servoRotate(self, thetas):
        self.angleToServo(thetas)
        #self.angleToServo(np.zeros((4,3)))
        for x in range(len(self._val_list)):
            
            if x>=0 and x<12:
                self._val_list[x] = (self._val_list[x]-26.36)*(1980/1500)
                #print(self._val_list[x], end=' ')
                #if x%3 == 2: print()
                print(self._val_list[x])

                if (self._val_list[x] > 180):
                    print("Over 180!!")
                    self._val_list[x] = 179
                    continue
                if (self._val_list[x] <= 0):
                    print("Under 0!!")
                    self._val_list[x] = 1
                    continue
                if x < 6:
                    self._kit.servo[x].angle = self._val_list[x]
                else:
                    self._kit2.servo[x].angle = self._val_list[x]


if __name__=="__main__":
    legEndpoints=np.array([[100,-100,87.5,1],[100,-100,-87.5,1],[-100,-100,87.5,1],[-100,-100,-87.5,1]])
    thetas = kn.initIK(legEndpoints) #radians
    
    controller = Controllers()

    # Get radian thetas, transform to integer servo angles
    # then, rotate servos
    controller.servoRotate(thetas)

    # Get AngleValues for Debugging
    svAngle = controller.getServoAngles()
    print(svAngle)

    # #plot at the end
    kn.plotKinematics()

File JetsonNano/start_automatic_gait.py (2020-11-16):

"""
Simulation of SpotMicroAI and it's Kinematics 
Use a keyboard to see how it works
Use keyboard-Button to switch betweek walk on static-mode
"""
from os import system, name 
import sys
sys.path.append("..")

import matplotlib.animation as animation
import numpy as np
import time
import math
import datetime as dt
import keyboard
import random

import Kinematics.kinematics as kn
import spotmicroai
import servo_controller

from multiprocessing import Process
from Common.multiprocess_kb import KeyInterrupt
from Kinematics.kinematicMotion import KinematicMotion, TrottingGait

rtime=time.time()

def reset():
    global rtime
    rtime=time.time()    

robot=spotmicroai.Robot(False,False,reset)
controller = servo_controller.Controllers()

# TODO: Needs refactoring
speed1=240
speed2=170
speed3=300

speed1=322
speed2=237
speed3=436

spurWidth=robot.W/2+20
stepLength=0
stepHeight=72

# Initial End point X Value for Front legs 
iXf=120

walk=False

def resetPose():
    # TODO: globals are bad
    global joy_x, joy_z, joy_y, joy_rz, joy_z
    joy_x, joy_y, joy_z, joy_rz = 128, 128, 128, 128

# define our clear function 
def consoleClear(): 
  
    # for windows 
    if name == 'nt': 
        _ = system('cls') 
  
    # for mac and linux(here, os.name is 'posix') 
    else: 
        _ = system('clear') 



Lp = np.array([[iXf, -100, spurWidth, 1], [iXf, -100, -spurWidth, 1],
[-50, -100, spurWidth, 1], [-50, -100, -spurWidth, 1]])

motion=KinematicMotion(Lp)
resetPose()

trotting=TrottingGait()

def main(id, command_status):
    jointAngles = []
    while True:
        xr = 0.0
        yr = 0.0

        # Reset when robot pose become strange
        # robot.resetBody()
    
        ir=xr/(math.pi/180)
        
        d=time.time()-rtime

        # robot height
        height = 40

        # calculate robot step command from keyboard inputs
        result_dict = command_status.get()
        print(result_dict)
        command_status.put(result_dict)

        # wait 3 seconds to start
        if result_dict['StartStepping']:
            currentLp = trotting.positions(d-3, result_dict)
            robot.feetPosition(currentLp)
        else:
            robot.feetPosition(Lp)
        #roll=-xr
        roll=0
        robot.bodyRotation((roll,math.pi/180*((joy_x)-128)/3,-(1/256*joy_y-0.5)))
        bodyX=50+yr*10
        robot.bodyPosition((bodyX, 40+height, -ir))

        # Get current Angles for each motor
        jointAngles = robot.getAngle()
        print(jointAngles)
        
        # First Step doesn't contains jointAngles
        if len(jointAngles):
            # Real Actuators
            controller.servoRotate(jointAngles)
            
            # # Plot Robot Pose into Matplotlib for Debugging
            # TODO: Matplotplib animation
            # kn.initFK(jointAngles)
            # kn.plotKinematics()

        robot.step()
        consoleClear()


if __name__ == "__main__":
    try:
        # Keyboard input Process
        KeyInputs = KeyInterrupt()
        KeyProcess = Process(target=KeyInputs.keyInterrupt, args=(1, KeyInputs.key_status, KeyInputs.command_status))
        KeyProcess.start()

        # Main Process 
        main(2, KeyInputs.command_status)
        
        print("terminate KeyBoard Input process")
        if KeyProcess.is_alive():
            KeyProcess.terminate()
    except Exception as e:
        print(e)
    finally:
        print("Done... :)")

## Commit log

2020-09-26 First Commit : forked from User Florian Wilk
    [B_cover.stl, F_cover.stl, F_cover_orig.stl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]
2020-09-26 Update: kinematics test ongiong
2020-09-26 kinematics.py edited to provide thetas. Controller attached.
2020-09-26 Update: 시뮬레이션 구조 파악 중
2020-09-26 Update: 매개변수 이해 완료
2020-09-26 Update: keyboard handler 달기 전
2020-09-26 Update: pybullet 제거 작업 시작
2020-09-26 Update: 시뮬레이션에서 필요한 부분만 추출 완료 example_automatic_gait.py 에 담김
2020-09-30 Update: 0x41 Motor Driver Mode adapted
2020-09-30 Update: Forward Kinematics Plot done
2020-10-01 Feat: Gait Loop and Servo Motor Integration done
2020-10-01 Fix: Offset 을 안넣어줬다
    [servo_controller.py]
2020-10-03 STL file uploaded / gitignore added
2020-10-08 Update: 정지 상태에서는 걷지 않도록 함
2020-10-31 motor calibration + pwm
2020-11-07 Update: Slow Walk but Not Work
    [servo_controller.py, start_automatic_gait.py]
2020-11-09 Update servo_controller.py
    Comment added
2020-11-16 Useless STL Folder deleted
    [B_cover.stl, F_cover.stl, F_cover_orig.stl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]
2020-11-18 lecture code attached
2020-11-19 pybullet tutorial added
    [simplecar.urdf]
2021-01-22 Update : Lecture Version STL added
2021-01-22 Update : STL updated
2021-01-22 Create STEPfiles_Bodyparts
    STEPfiles_Bodyparts : Top/Bottom plate, Side plates, Shoulder parts
2021-01-22 Customed CAD Files
2021-01-22 Update: STEP Files re-added / STL Files updated to zip file
    [B_cover.stl, Bottom_modi(long).stp, F_cover.stl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]
2021-03-26 Fix : spotmicroai_gen.urdf.xml stl import error
    [B_cover.stl, F_cover.stl, F_cover_orig.stl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]
2021-04-28 Add: servo_controller_fix.py Update: servo_controller.py
    - Library for servo_controller_fix,
    has been changed to PCA9685 from ServoKit.
    - Code cleanup. Unnecessary lines has been erased.
2021-04-28 Fix: Minor debug for servo_controller_fix.py
    [servo_controller_fix.py]
2021-08-13 Update for servokit
